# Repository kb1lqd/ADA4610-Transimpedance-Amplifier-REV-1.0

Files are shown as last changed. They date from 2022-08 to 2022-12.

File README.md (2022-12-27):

Notes

# 2022-08-23

* Soldered the board together
* It works! But I did find some minor errors.
* The voltage output varies as expected with light over a wide range

## Errors
* D1 footprint pin 1 assingment is backwards, this resulted in the diode being backwards
* The resulting current from the device is quite large resulting in the second amplifier stage being saturate in a lit room, I removed R7 to create a voltage follower and this alleviate the issues for now
* Placing the output on a scope it's clear there is a HF oscillation at 2.24mHz
** NOTE that the oscillation appears to be only on the 2nd stage output and not the first stage. Note that the second stage is now a voltage follower

# 2022-08-24

* Placed a 33pF capacitor across R8 and this stopped the oscillation
* I repopulated R7 with a 1K resistor
* There is some very very high frequency noise but pretty negligable it seems
* It works! I can definetley see an IRDA remote control signal at ~37KHz carrier
* It seems like if I want to use this in a bright room I'm going to have to turn the gains down
** Which is better - the TIA or the second stage?

# 2022-10-03

I've built up a bit of infrastructure around this TIA:
* Headphone amplifier to output the audio frequencies directly into headphones
* Listened to external light sources with a len assembly 3 miles away
* Built a simple audio light transmitter

I've noticed a faire bit of noise in the circuit. Hooking a scope up to the TP output I see a fairly complex oscillation between 30KHz and 97KHz. There is a different noise on the TIA output directly much smaller prior to the line driver amplifier.

**Noise on the TIA PCB 50 Ohm Output***

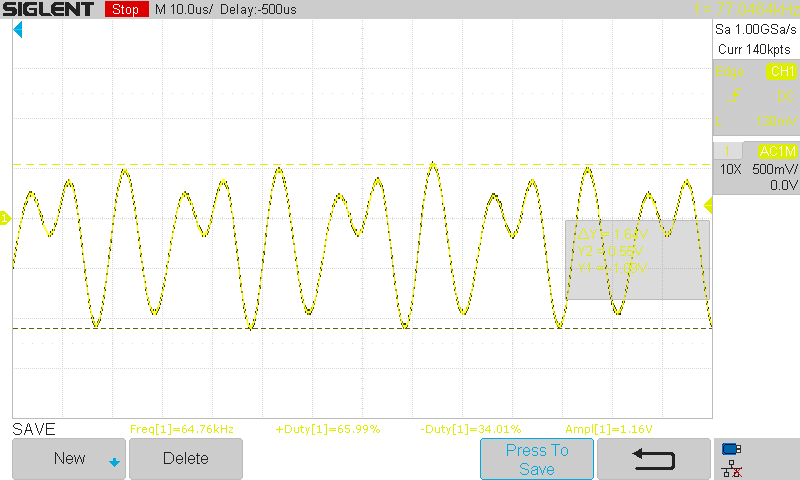
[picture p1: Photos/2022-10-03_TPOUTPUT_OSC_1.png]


**Noise on the TIA Output directly**

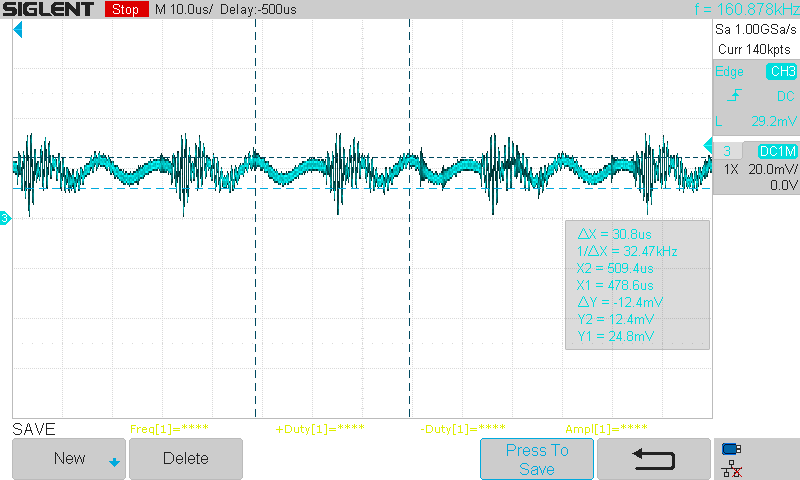
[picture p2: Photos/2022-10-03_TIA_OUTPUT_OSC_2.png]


I can see and hear the 120 Hz hum from my indoor (dim) lights that this noise is on top of.

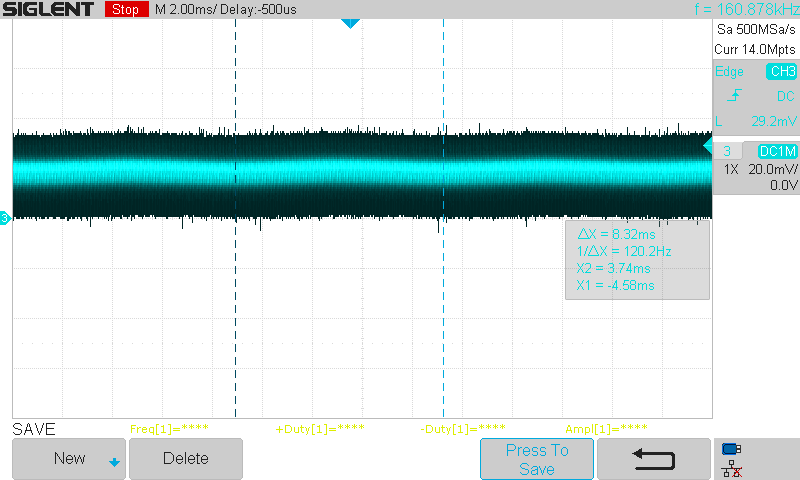
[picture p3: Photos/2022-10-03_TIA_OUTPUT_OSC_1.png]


# 2022-10-04

* I put the recommended bulk capacitors on the PYBE20-Q24-D5-T - No significant change but leaving them There
* I think it may have knocked a bit of the switching noise off
  * I defintely see a 32KHz DC/DC switching noise but it's near my scopes limit
  * It is seen on the preamp section op-amp bulk capacitors and in the TIA signal itself - It may be ground noise coming through the GND clip...?
  * Placing bulk capacitance on the preamp - no effect
* I added a 15pF capacitor to C2 to help bypass any HF signals past the 0 ohm or stabalize the POS input when in a higher impedance configuration
* I changed the Cf on the TIA (C4) from 3.3pF to 33pF for improved stability - No significant change - The nosie see is the same and defintely switching noise (likley on GND)
* I iterated a Cf across R8 and found that a 1nF completely kills the oscillation see - Tried ~200pF with good results but sign reduced from ~300mV to 60mV peak to peak.

I'm getting subjectively reduced noise!

I can clearly head music and tones from an online frequency generator through the transmitter (Although I don't think it's fully modulating the LED)

I listened to a few signals:

**iPhone FaceID Pulses**

The pulses are very clear (DC Coupled scope after the DC blocking capacitor) with a rise time of 92us (~3KHz)

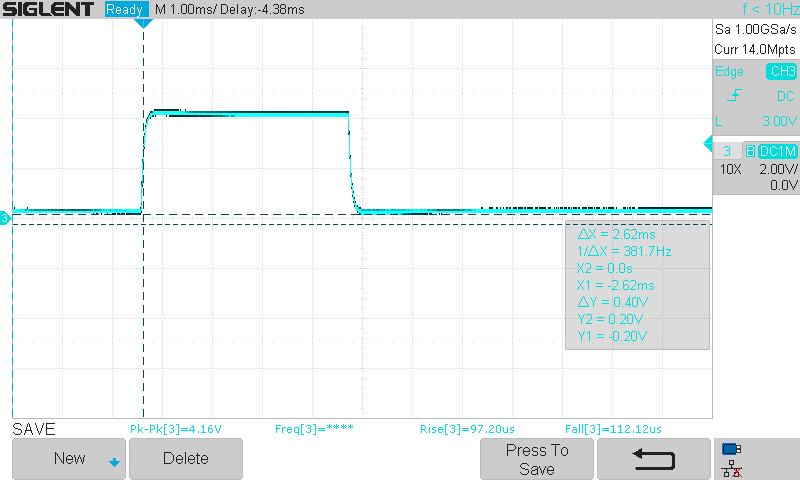
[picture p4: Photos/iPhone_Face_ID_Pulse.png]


**Optical Mouse LED/LASER**

This was much quicker of a signal and measured around 3.6us which is approximately (0.35/Tr) 100KHz bandwidth. I don't know what this signal looks linear.

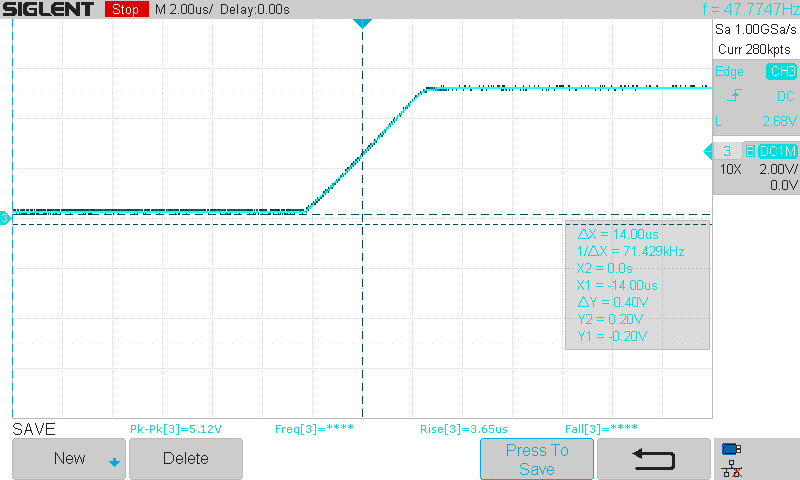
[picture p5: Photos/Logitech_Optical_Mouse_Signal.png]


# 2022-12-26

* I soldered a new TIA PCB together (Ver1.1) with just U1 TIA. I found that the TIA was stable at RF=10K and CF=6.6pF with the diode in photovoltaic mode (grounded) and the TIA V+ referenced to GND. This configuration did require U1 to operate with a split rail.
* I was wrong in the prior testing and it seemed that the U2 second stage was LPF'ing the 37KHz IRDA signals. I was clearly able to see the IRDA waveforms (still looked RC charged/discharged but that might have been the IR remote itself - More investigation needed.

# To-Do
* [DONE] Track down oscillation
* [DONE] Detect light pulses in the scope and observe the results
* Detemirne rough frequency response - even if simulated with updated values (37KHz carrier pulses looked pretty rounded) - This may inform a reduction in capacitances or resistances)

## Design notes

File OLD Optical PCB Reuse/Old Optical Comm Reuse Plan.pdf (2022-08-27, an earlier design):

# Old Optical Comm Reuse Plan

## Headphone Audio - Aug 2022

## TPA6111A2D Headphone Amp

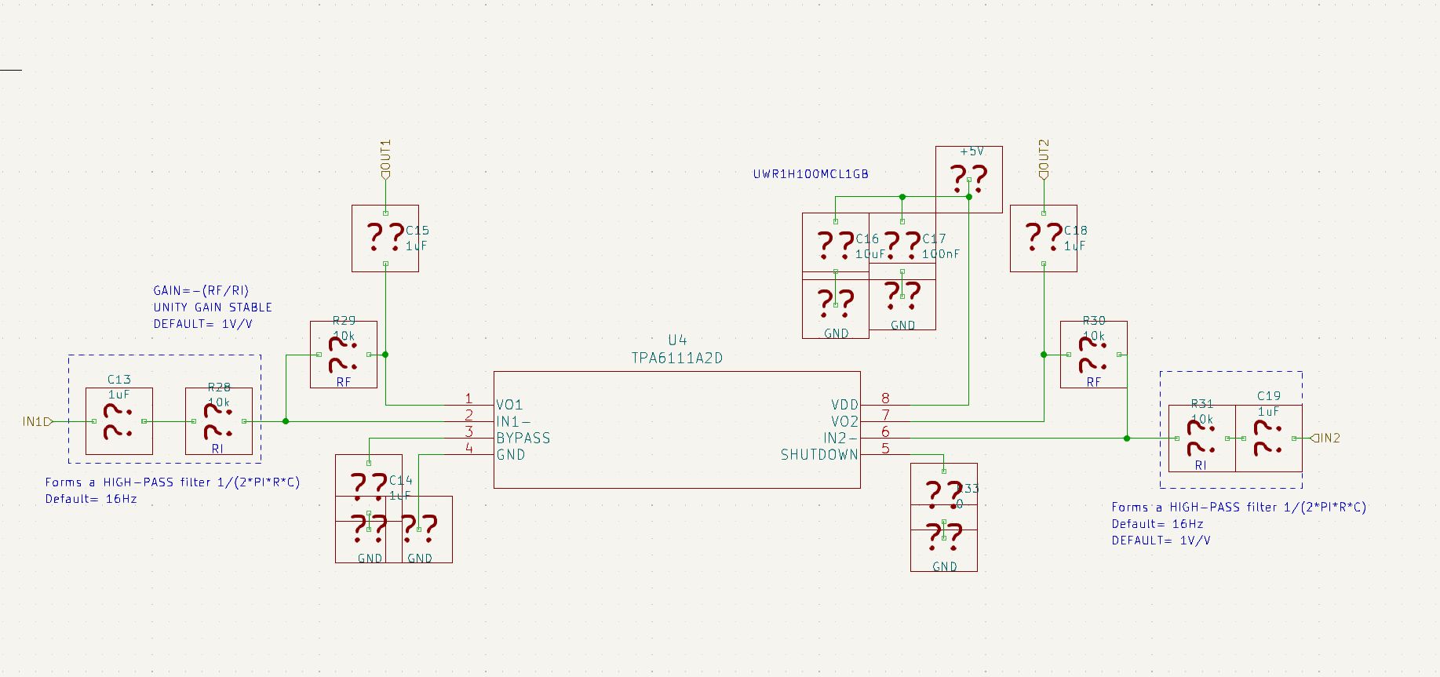
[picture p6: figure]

## Where to tap in

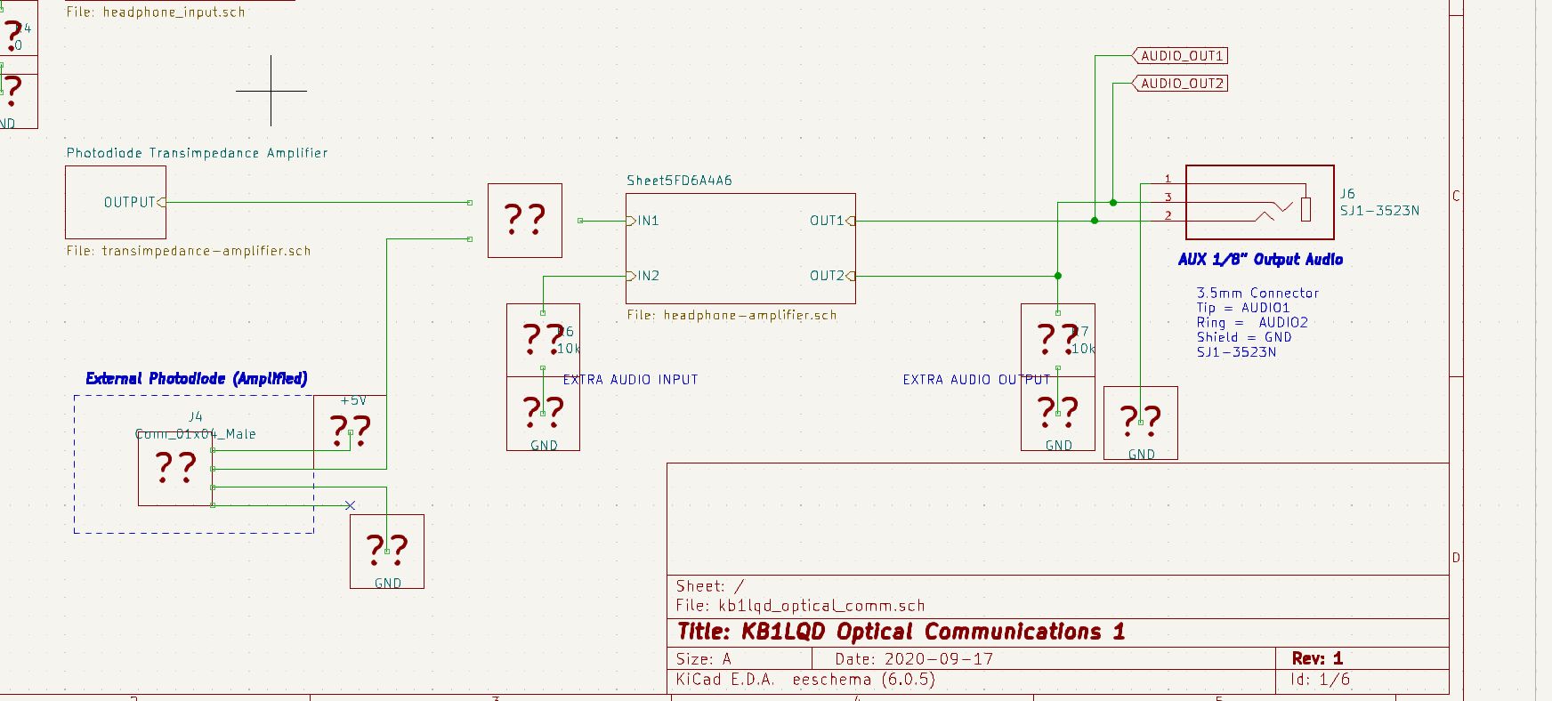
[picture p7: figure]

- Use connector J4 to get TIA signal in
- Jump the SW prior to IN1
- Short IN1 to IN2 for dual headphone?
- Use J6

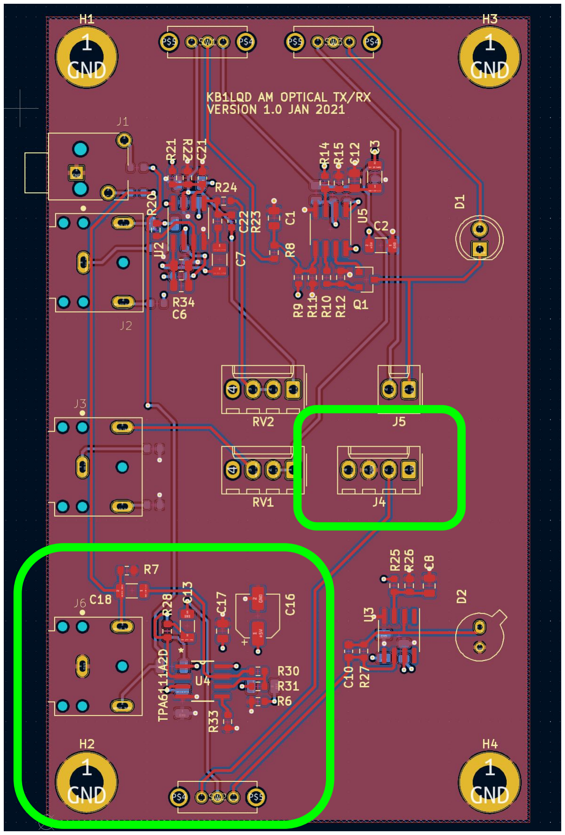
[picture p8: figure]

- J4 can input
- Signal
- +5V
- GND
●

## LED Driver?

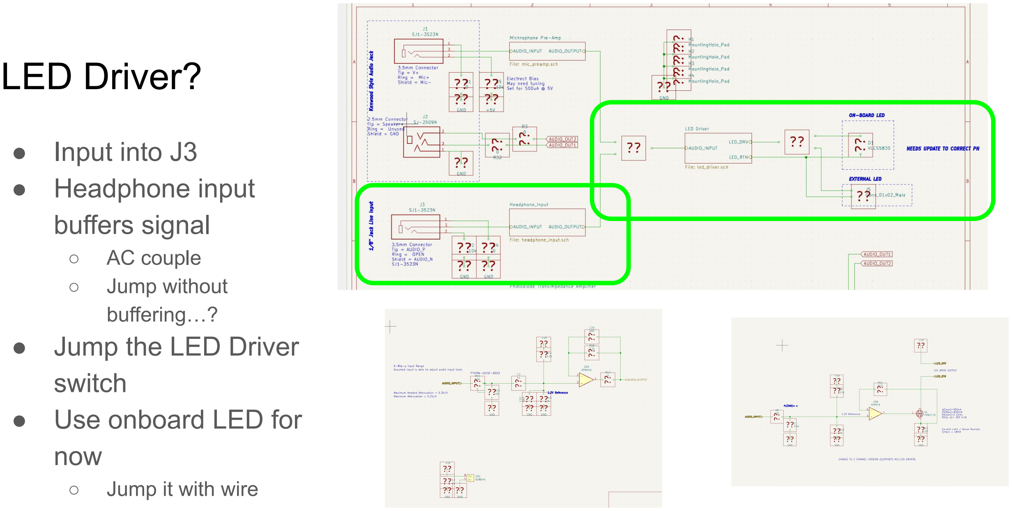
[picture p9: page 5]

- Input into J3
- Headphone input
buffers signal
- AC couple
- Jump without
buffering…?
- Jump the LED Driver
switch
- Use onboard LED for
now
- Jump it with wire

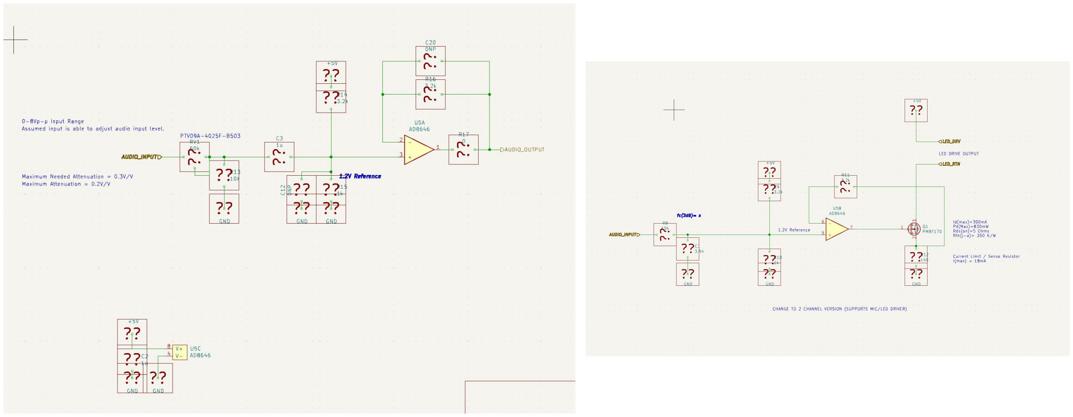
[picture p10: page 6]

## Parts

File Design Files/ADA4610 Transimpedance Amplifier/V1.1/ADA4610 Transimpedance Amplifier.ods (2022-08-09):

Item | Qty | Reference(s) | Value | PN Assigned | From Where? | Package | Footprint Done? | Ordered?
1 | 2 | C1, C3 | 1u | C1206X105M1RAC7800 | Brent’s Inventory | 1206 | Yes | N/A
2 | 1 | C2 | 100n | C0805C104Z4VAC7800 | Digikey | 805 | Yes | In List
3 | 1 | C4 | 3.3p | 06035A3R3KAT2A | Digikey | 603 | Yes | In List
4 | 1 | C5 | 10u | CL32A106KBJNNNE | Digikey | 1210 | Yes | In List
5 | 2 | C6, C7 | 1u | C1206X105M1RAC7800 | Brent’s Inventory | 1206 | Yes | N/A
6 | 1 | D1 | ODD-1W | ODD-1W | Brent’s Inventory | ODD-1W |  | N/A
7 | 4 | H1, H2, H3, H4 | MountingHole |  | Brent’s Inventory | N/A | Yes | N/A
8 | 1 | J1 | Conn_01x03_Male | KK | Brent’s Inventory | KK | Yes | N/A
9 | 1 | J2 | Conn_Coaxial | CON-EDGE-SMA-5 | Brent’s Inventory | CON-EDGE-SMA-5 |  | N/A
10 | 3 | R1, R2, R5 | 0 | RC0603FR-130RL | Brent’s Inventory | 603 | Yes | N/A
11 | 2 | R3, R4 | 10k | RC0603FR-1010KL | Brent’s Inventory | 603 | Yes | N/A
12 | 1 | R6 | 100k | RC0805JR-07100KL | Brent’s Inventory | 805 | Yes | N/A
13 | 1 | R7 | 1k | RC0603FR-131KL | Brent’s Inventory | 603 | Yes | N/A
14 | 1 | R8 | 49.9k | ERJ-PB6D4992V | Digikey | 805 | Yes | In List
15 | 2 | R9, R10 | 49.9 | ERJ-6ENF49R9V | Digikey | 805 | Yes | In List
16 | 7 | TP1, TP2, TP3, TP4, TP5, TP6, TP7 | TestPoint | 36-5010-ND | Digikey | 36-5010-ND | Yes | In List
17 | 2 | U1, U2 | ADA4610-1xR |  | Brent’s Inventory | SOT-23-5 | Yes | N/A

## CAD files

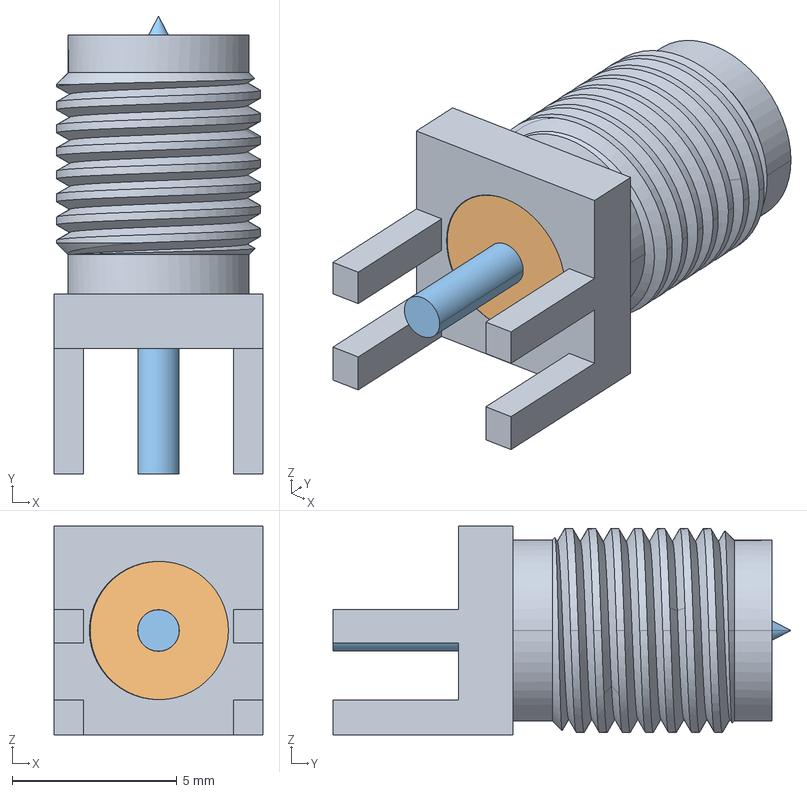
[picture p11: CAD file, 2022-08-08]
Components/CON-EDGE-SMARP-3D file - Copy.stp
6.35 x 13.9 x 6.35 mm
SMA-K-KE
JIAOLI
RP-ZHEN

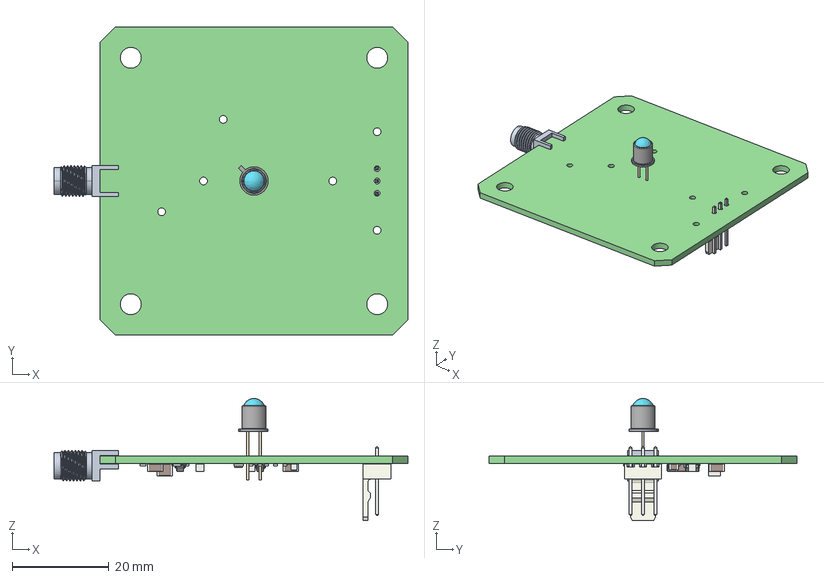
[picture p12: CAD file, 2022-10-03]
Design Files/ADA4610 Transimpedance Amplifier/V1.1/ADA4610 Transimpedance Amplifier.step
73.0 x 63.5 x 25.2 mm
ADA4610 Transimpedance Amplifier PCB

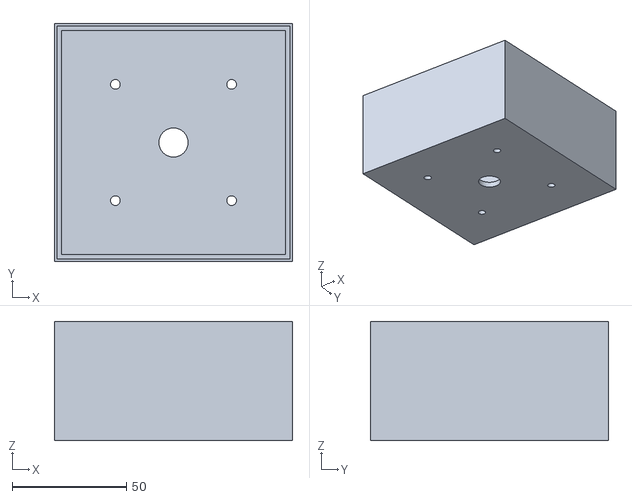
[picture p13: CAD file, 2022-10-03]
Design Files/ADA4610 Transimpedance Amplifier/V1.1/Lens Mount/Lensmount-ModelPCB Mount001.stl
104.0 x 104.0 x 52.0

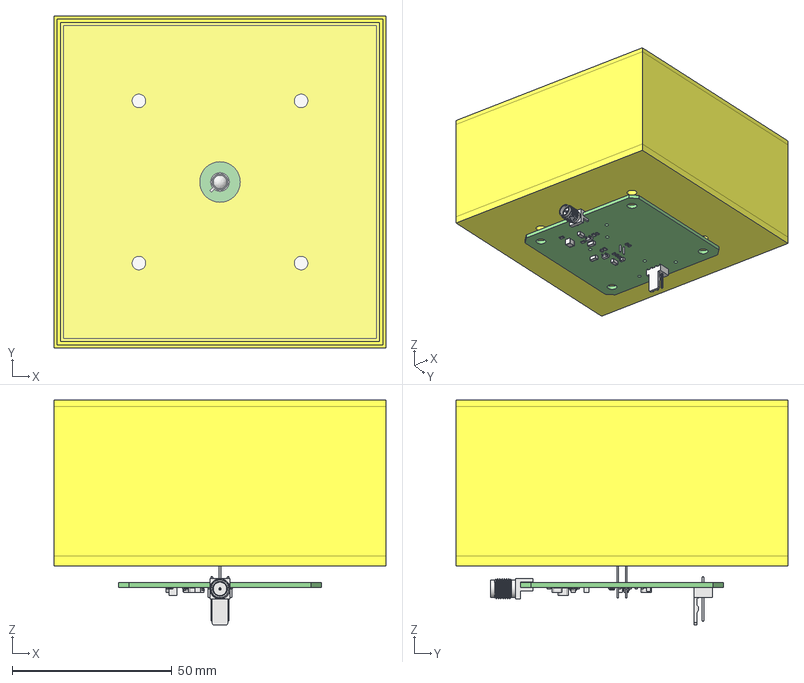
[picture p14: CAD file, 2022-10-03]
Design Files/ADA4610 Transimpedance Amplifier/V1.1/Lens Mount/Lensmount.FCStd
104.0 x 104.0 x 70.5 mm
PCB Mount
Lens
ADA4610 Transimpedance Amplifier PCB

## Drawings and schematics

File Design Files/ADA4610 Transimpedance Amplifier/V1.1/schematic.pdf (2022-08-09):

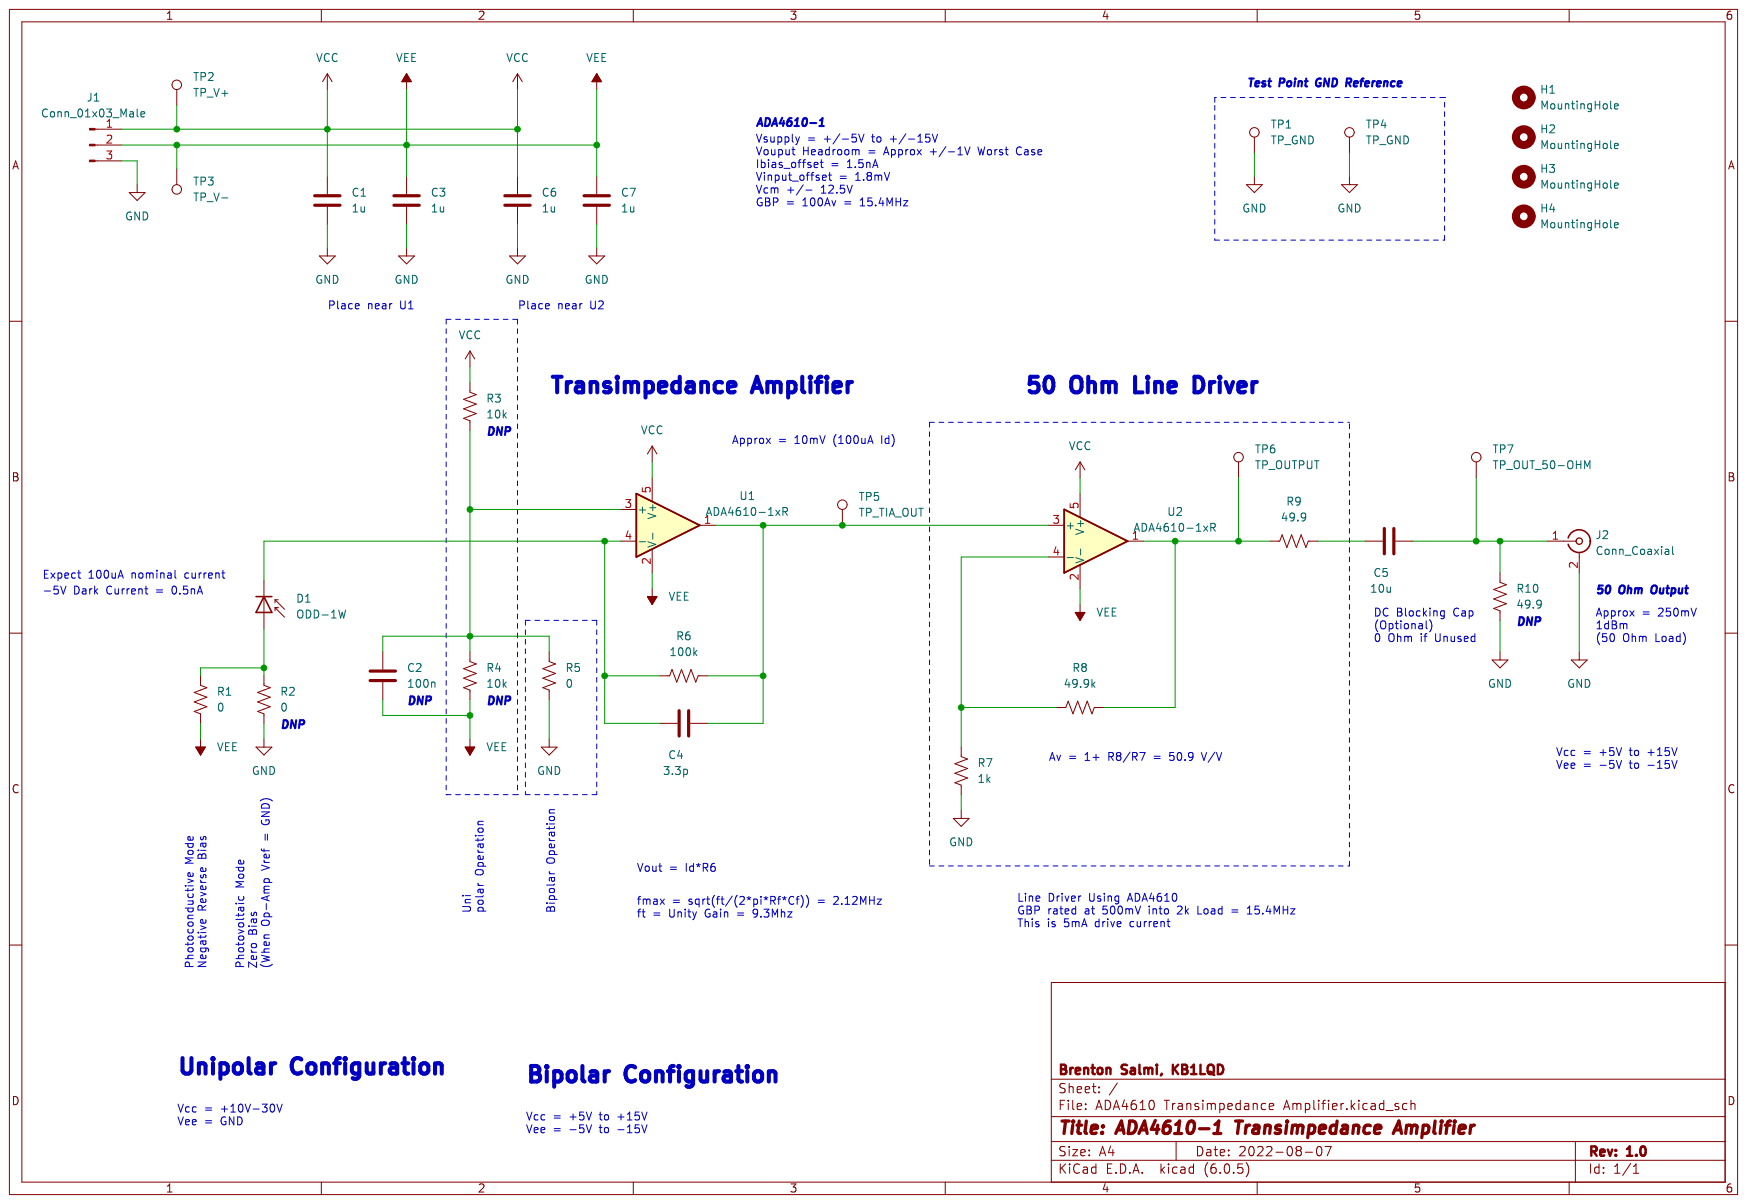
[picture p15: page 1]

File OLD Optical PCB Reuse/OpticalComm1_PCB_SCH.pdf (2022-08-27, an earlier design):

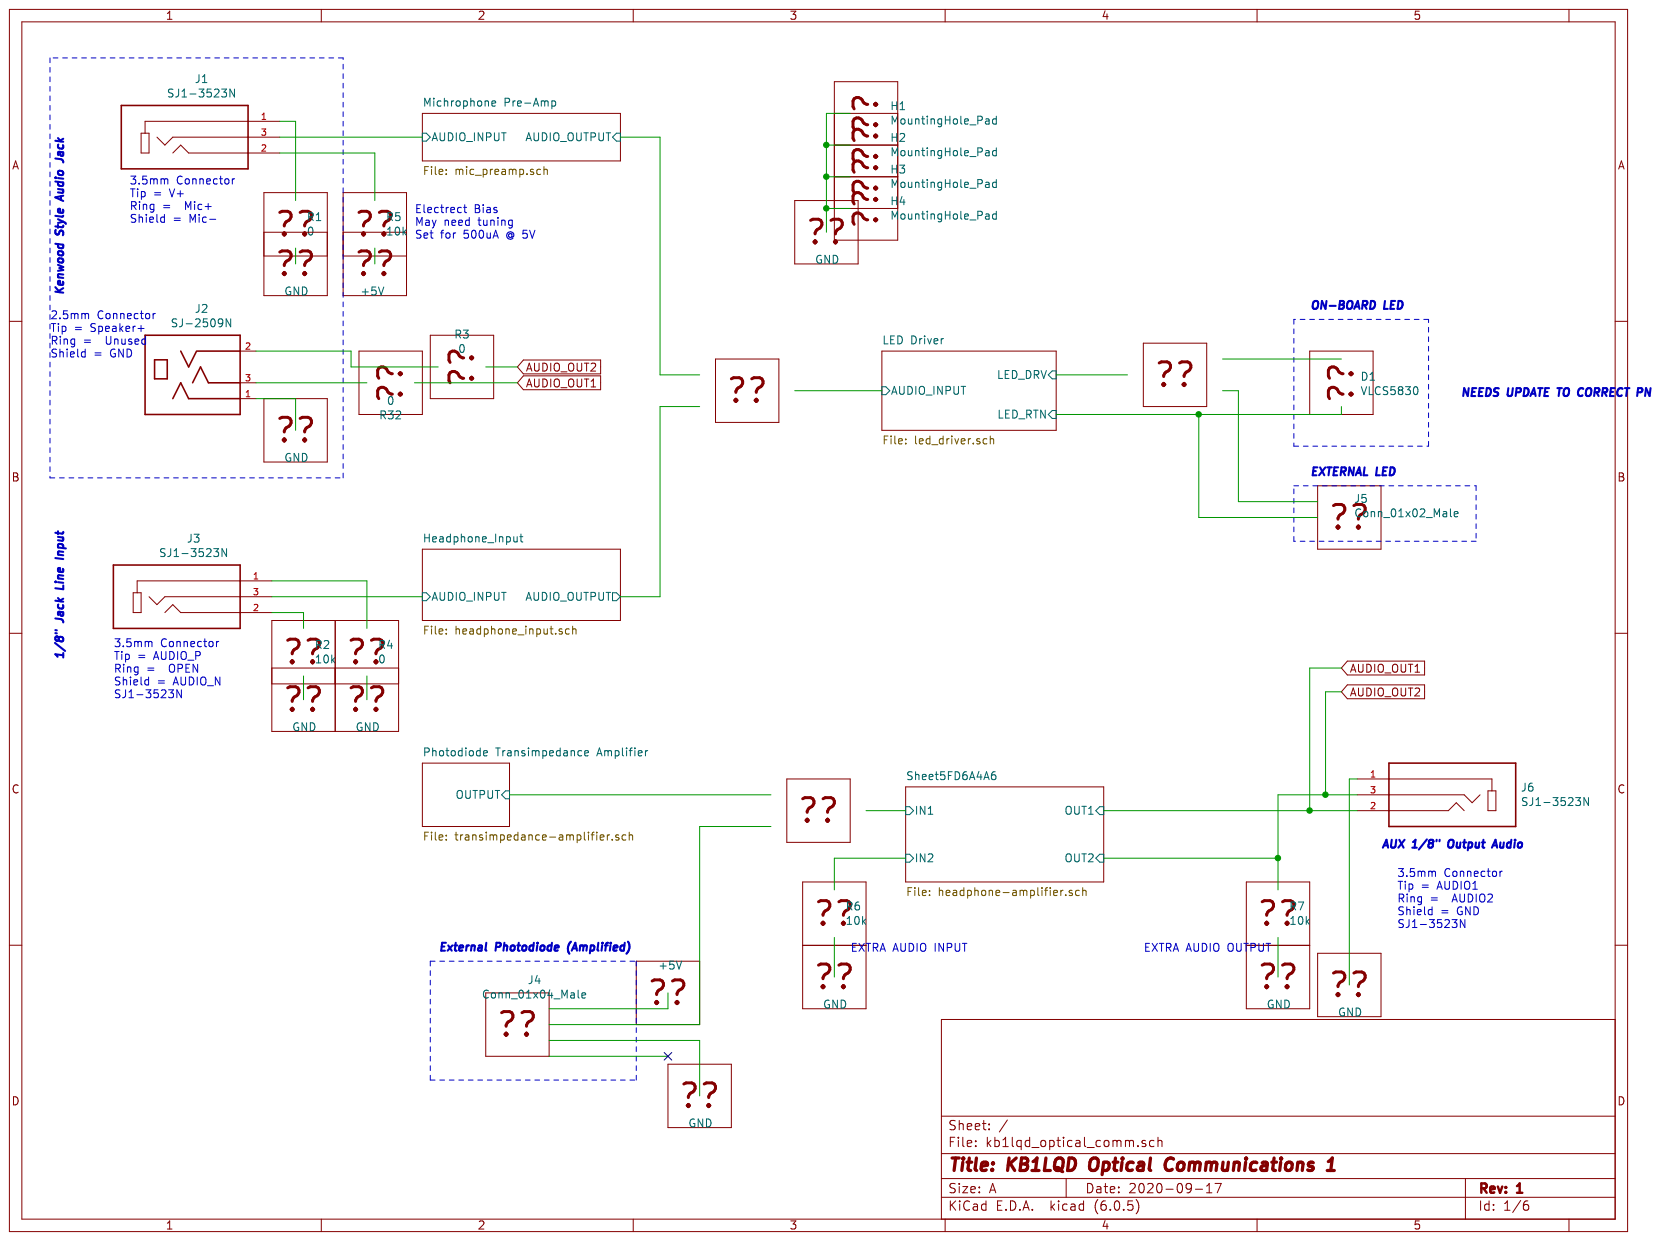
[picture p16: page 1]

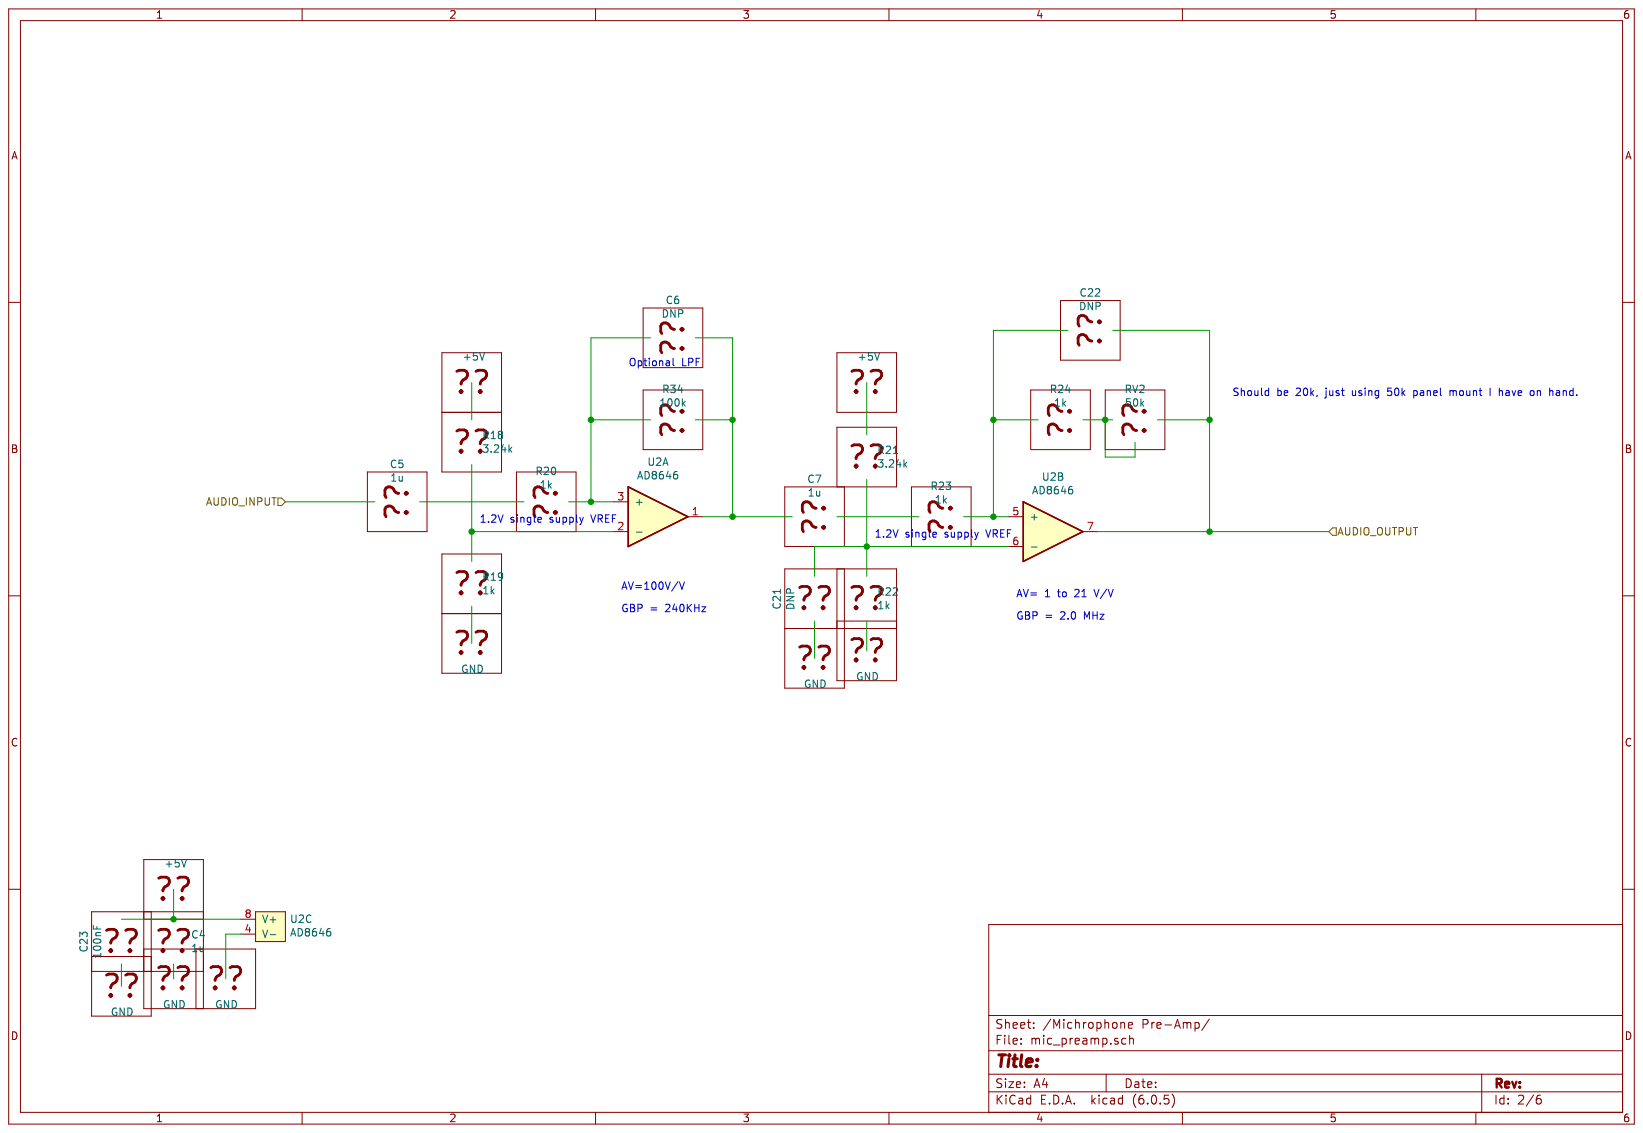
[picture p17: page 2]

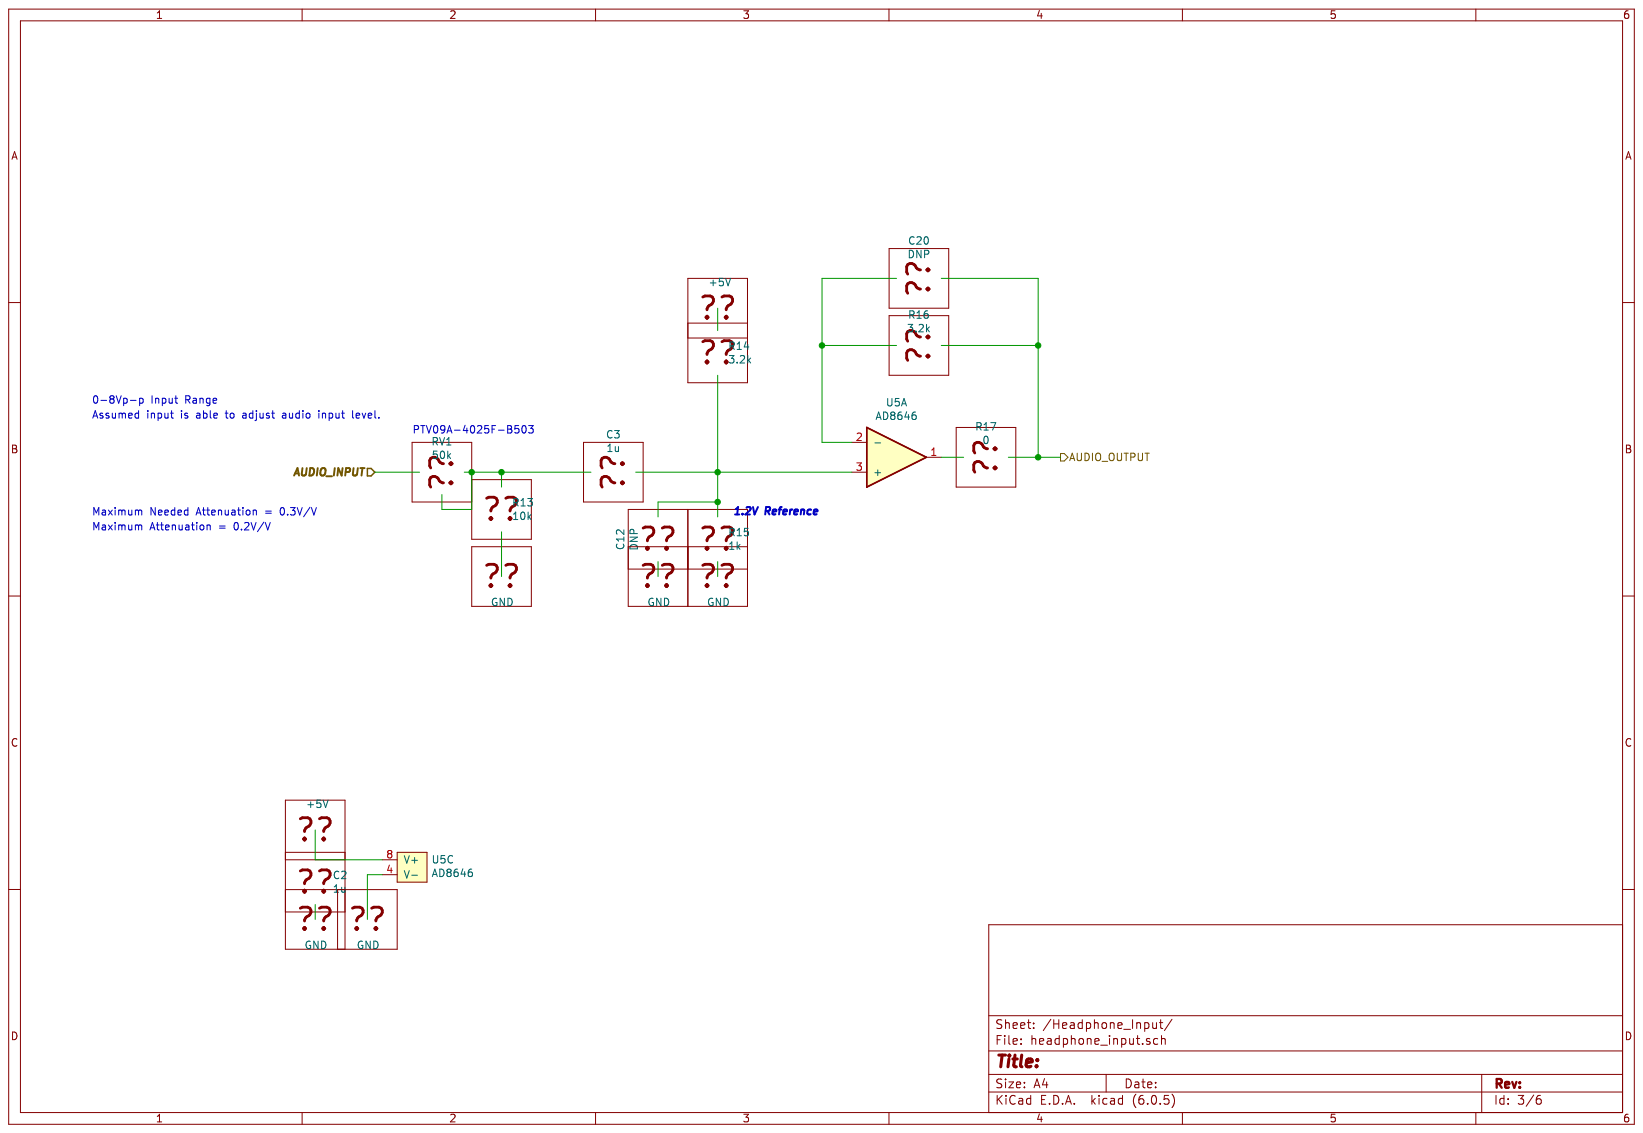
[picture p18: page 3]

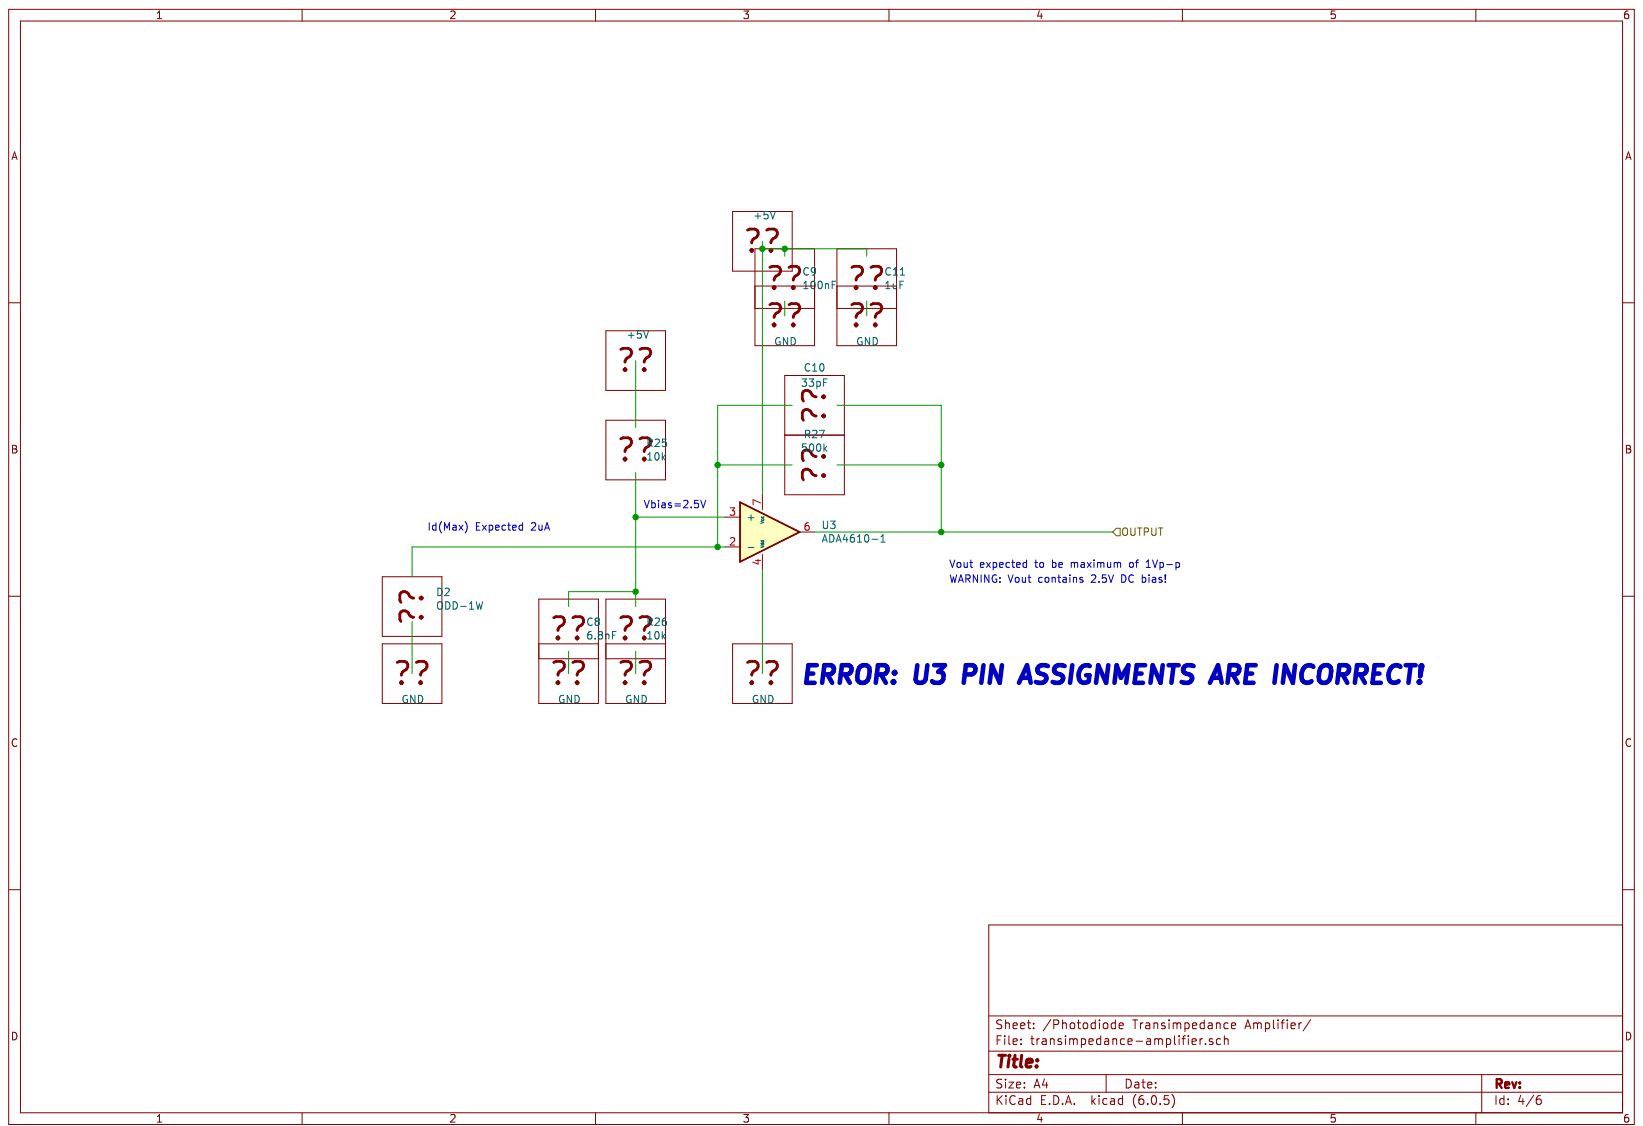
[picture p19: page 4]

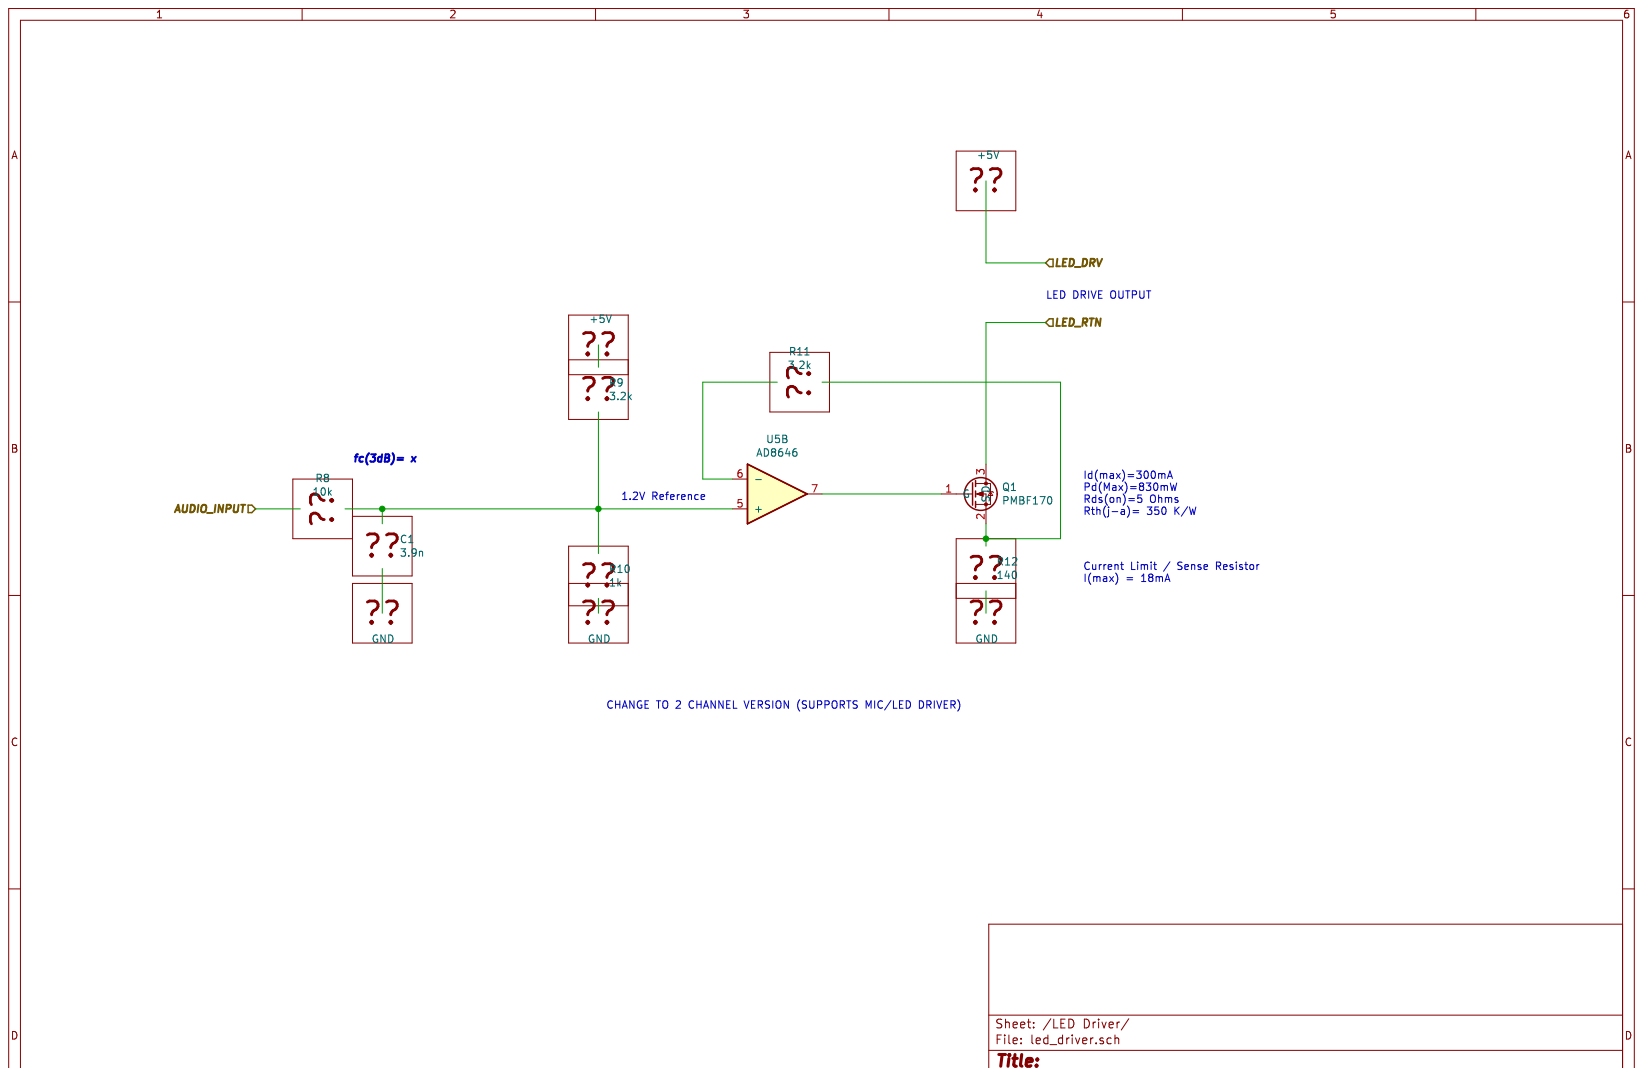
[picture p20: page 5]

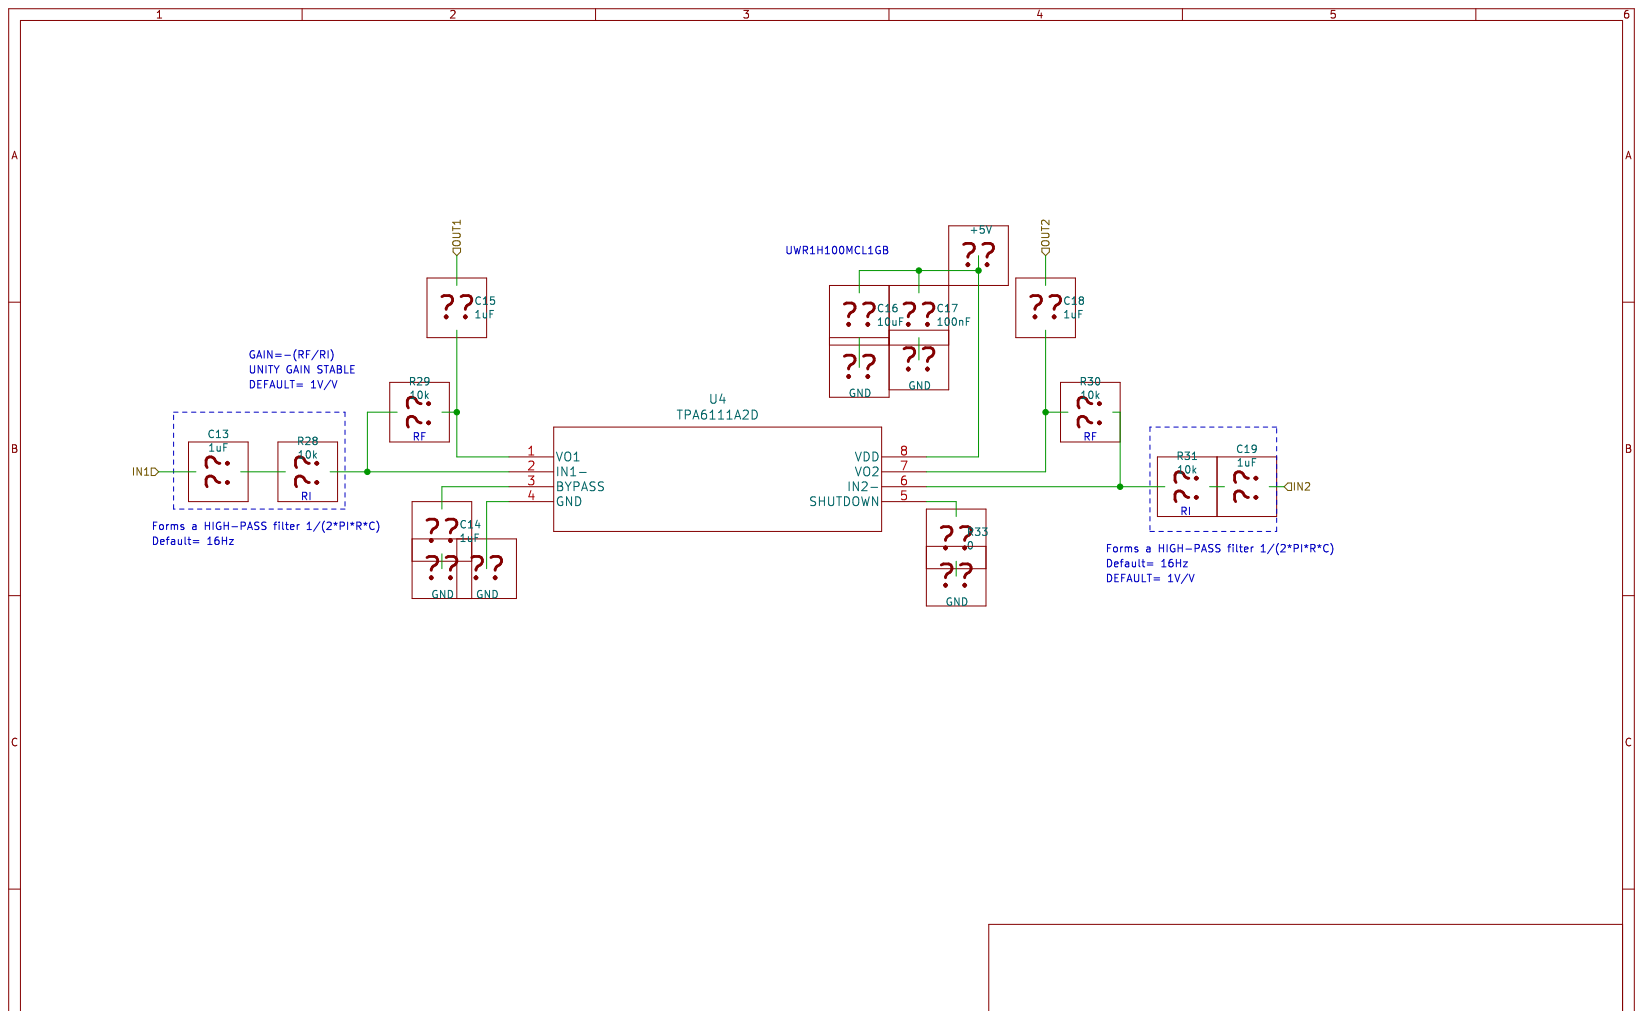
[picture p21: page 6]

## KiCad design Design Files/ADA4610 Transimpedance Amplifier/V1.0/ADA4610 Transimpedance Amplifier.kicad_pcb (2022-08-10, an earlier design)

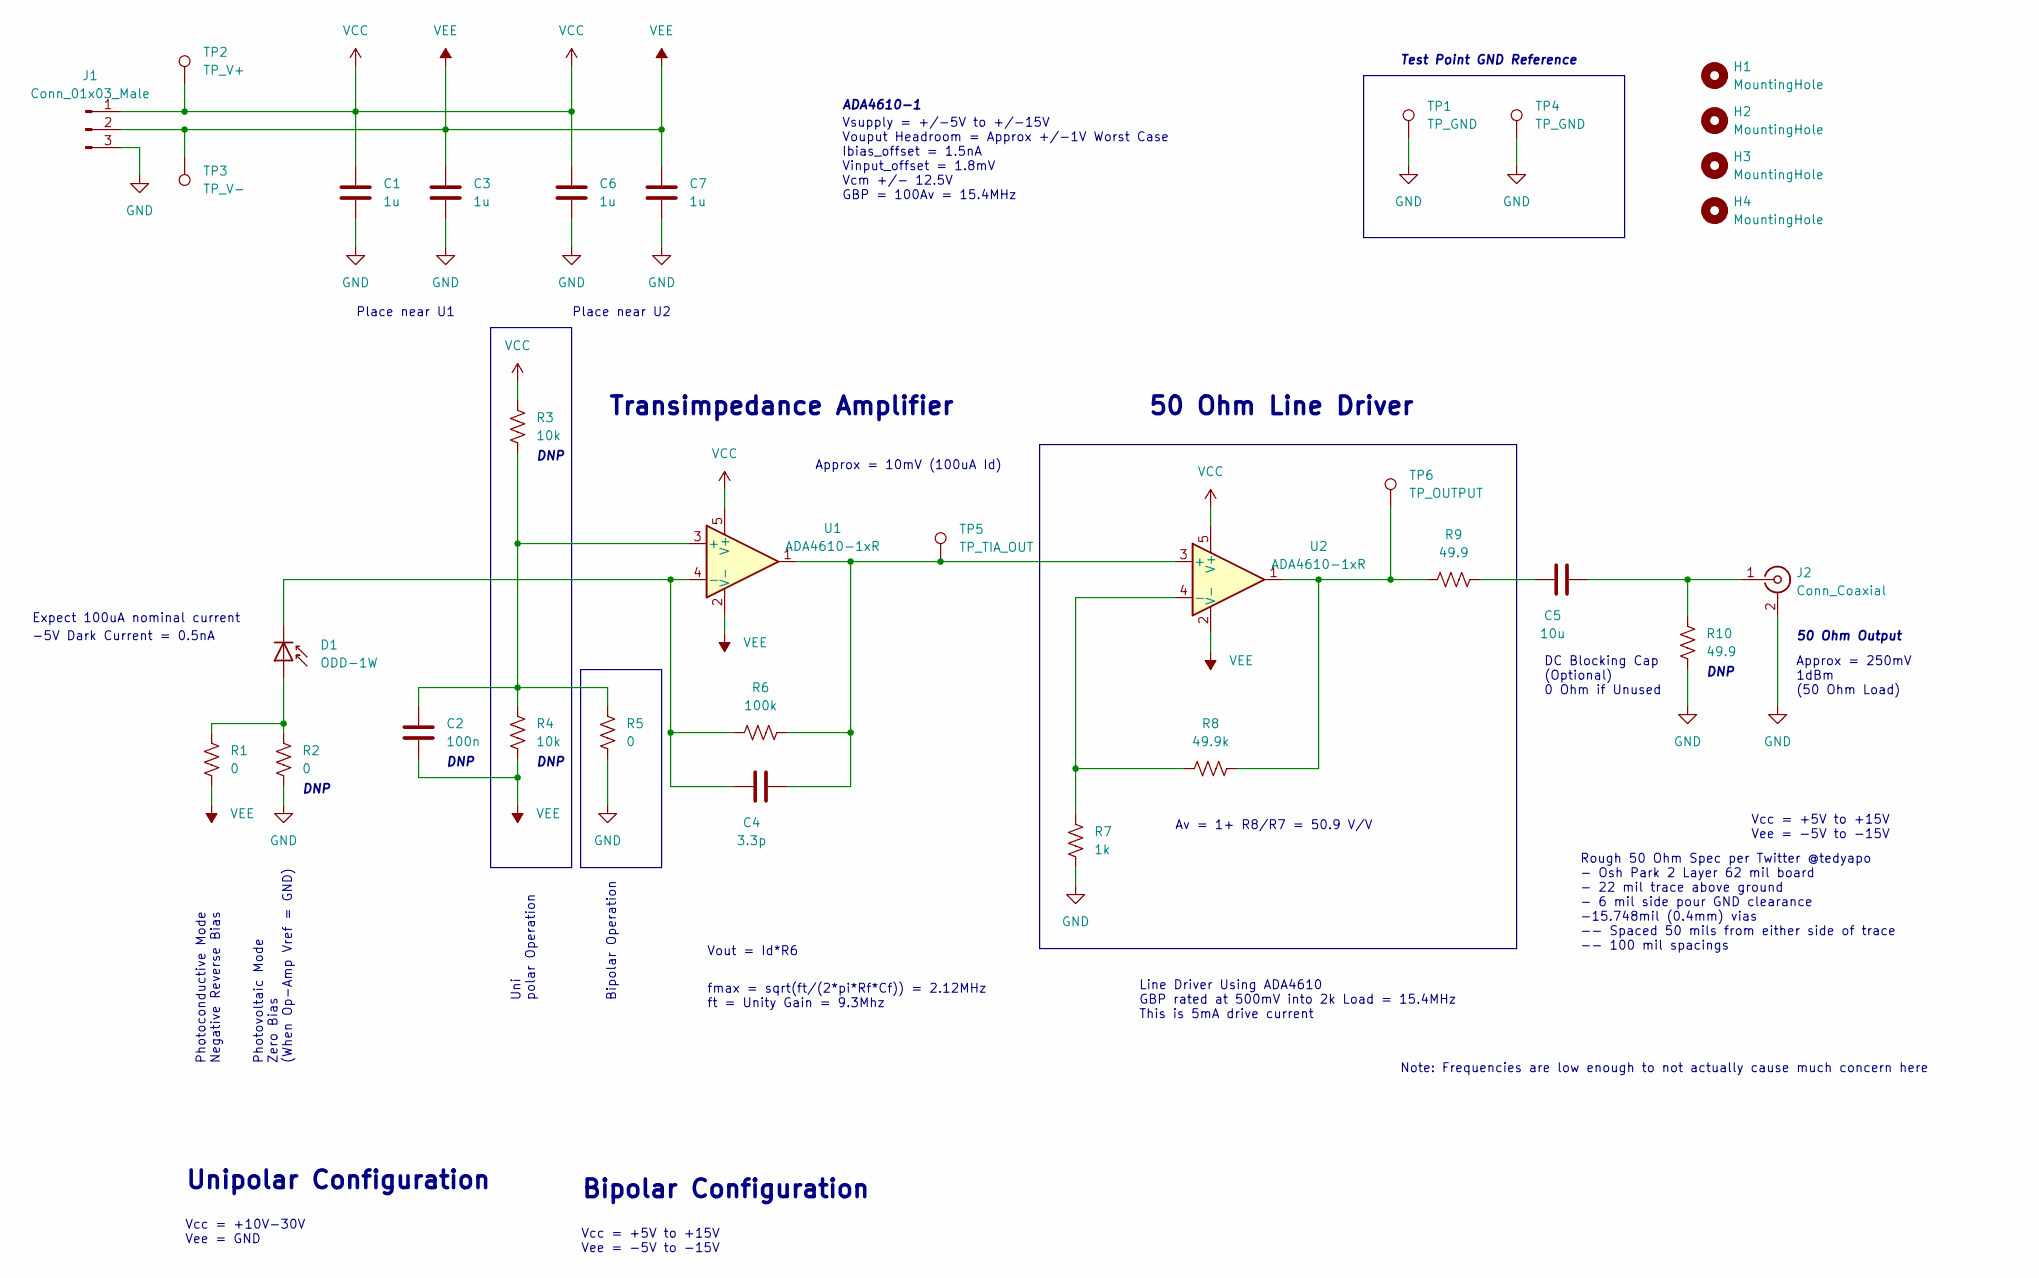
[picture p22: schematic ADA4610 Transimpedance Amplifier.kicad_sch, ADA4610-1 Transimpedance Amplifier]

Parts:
C1, C3, C6, C7: 1u; C_1206_3216Metric_Pad1.33x1.80mm_HandSolder
C2: 100n; C_0805_2012Metric_Pad1.18x1.45mm_HandSolder
C4: 3.3p; C_0603_1608Metric_Pad1.08x0.95mm_HandSolder
C5: 10u; C_1210_3225Metric_Pad1.33x2.70mm_HandSolder
D1: ODD-1W; TO-18-2_Lens_Centered
H1, H2, H3, H4: MountingHole; MountingHole_4.3mm_M4
J1: Conn_01x03_Male; Molex_KK-254_AE-6410-03A_1x03_P2.54mm_Vertical
J2: Conn_Coaxial; RFSOLUTIONS_CON-SMA-EDGE-S
R1, R2, R5: 0; R_0603_1608Metric_Pad0.98x0.95mm_HandSolder
R3, R4: 10k; R_0603_1608Metric_Pad0.98x0.95mm_HandSolder
R6: 100k; R_0805_2012Metric_Pad1.20x1.40mm_HandSolder
R7: 1k; R_0603_1608Metric_Pad0.98x0.95mm_HandSolder
R8: 49.9k; R_0805_2012Metric_Pad1.20x1.40mm_HandSolder
R9, R10: 49.9; R_0805_2012Metric_Pad1.20x1.40mm_HandSolder
TP1, TP4: TP_GND; TestPoint_Keystone_5010-5014_Multipurpose
TP2: TP_V+; TestPoint_Keystone_5010-5014_Multipurpose
TP3: TP_V-; TestPoint_Keystone_5010-5014_Multipurpose
TP5: TP_TIA_OUT; TestPoint_Keystone_5010-5014_Multipurpose
TP6: TP_OUTPUT; TestPoint_Keystone_5010-5014_Multipurpose
U1, U2: ADA4610-1xR; SOT-23-5

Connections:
GND: C1.1, C3.1, C6.1, C7.1, J1.3, J2.2 (Ext), R2.2, R5.2, R7.1, R10.2, TP1.1, TP4.1
unnamed: C2.2, R3.2, R4.1, R5.1, U1.3 (+)
unnamed: C4.1, D1.1 (K), R6.1, U1.4 (-)
unnamed: C4.2, R6.2, TP5.1, U1.1, U2.3 (+)
unnamed: C5.1, R9.1
unnamed: C5.2, J2.1 (In), R10.1
unnamed: D1.2 (A), R1.1, R2.1
unnamed: R7.2, R8.2, U2.4 (-)
unnamed: R8.1, R9.2, TP6.1, U2.1
VCC: C1.2, C6.2, J1.1, R3.1, TP2.1, U1.5 (V+), U2.5 (V+)
VEE: C2.1, C3.2, C7.2, J1.2, R1.2, R4.2, TP3.1, U1.2 (V-), U2.2 (V-)

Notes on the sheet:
50 Ohm Output
Uni polar Operation
50 Ohm Line Driver
DNP
DC Blocking Cap (Optional) 0 Ohm if Unused
Approx = 10mV (100uA Id)
Note: Frequencies are low enough to not actually cause much concern here
Vcc = +5V to +15V Vee = -5V to -15V
Line Driver Using ADA4610 GBP rated at 500mV into 2k Load = 15.4MHz This is 5mA drive current
Unipolar Configuration
Rough 50 Ohm Spec per Twitter @tedyapo - Osh Park 2 Layer 62 mil board - 22 mil trace above ground - 6 mil side pour GND clearance -15.748mil (0.4mm) vias -- Spaced 50 mils from either side of trace -- 100 mil spacings
Bipolar Operation
fmax = sqrt(ft/(2*pi*Rf*Cf)) = 2.12MHz ft = Unity Gain = 9.3Mhz
Vsupply = +/-5V to +/-15V Vouput Headroom = Approx +/-1V Worst Case Ibias_offset = 1.5nA Vinput_offset = 1.8mV Vcm +/- 12.5V GBP = 100Av = 15.4MHz
ADA4610-1
Test Point GND Reference
Place near U2
Vout = Id*R6
Photovoltaic Mode Zero Bias (When Op-Amp Vref = GND)
Photoconductive Mode Negative Reverse Bias
Expect 100uA nominal current
Transimpedance Amplifier
Av = 1+ R8/R7 = 50.9 V/V
Bipolar Configuration
-5V Dark Current = 0.5nA
Approx = 250mV 1dBm (50 Ohm Load)
Vcc = +10V-30V Vee = GND
Place near U1

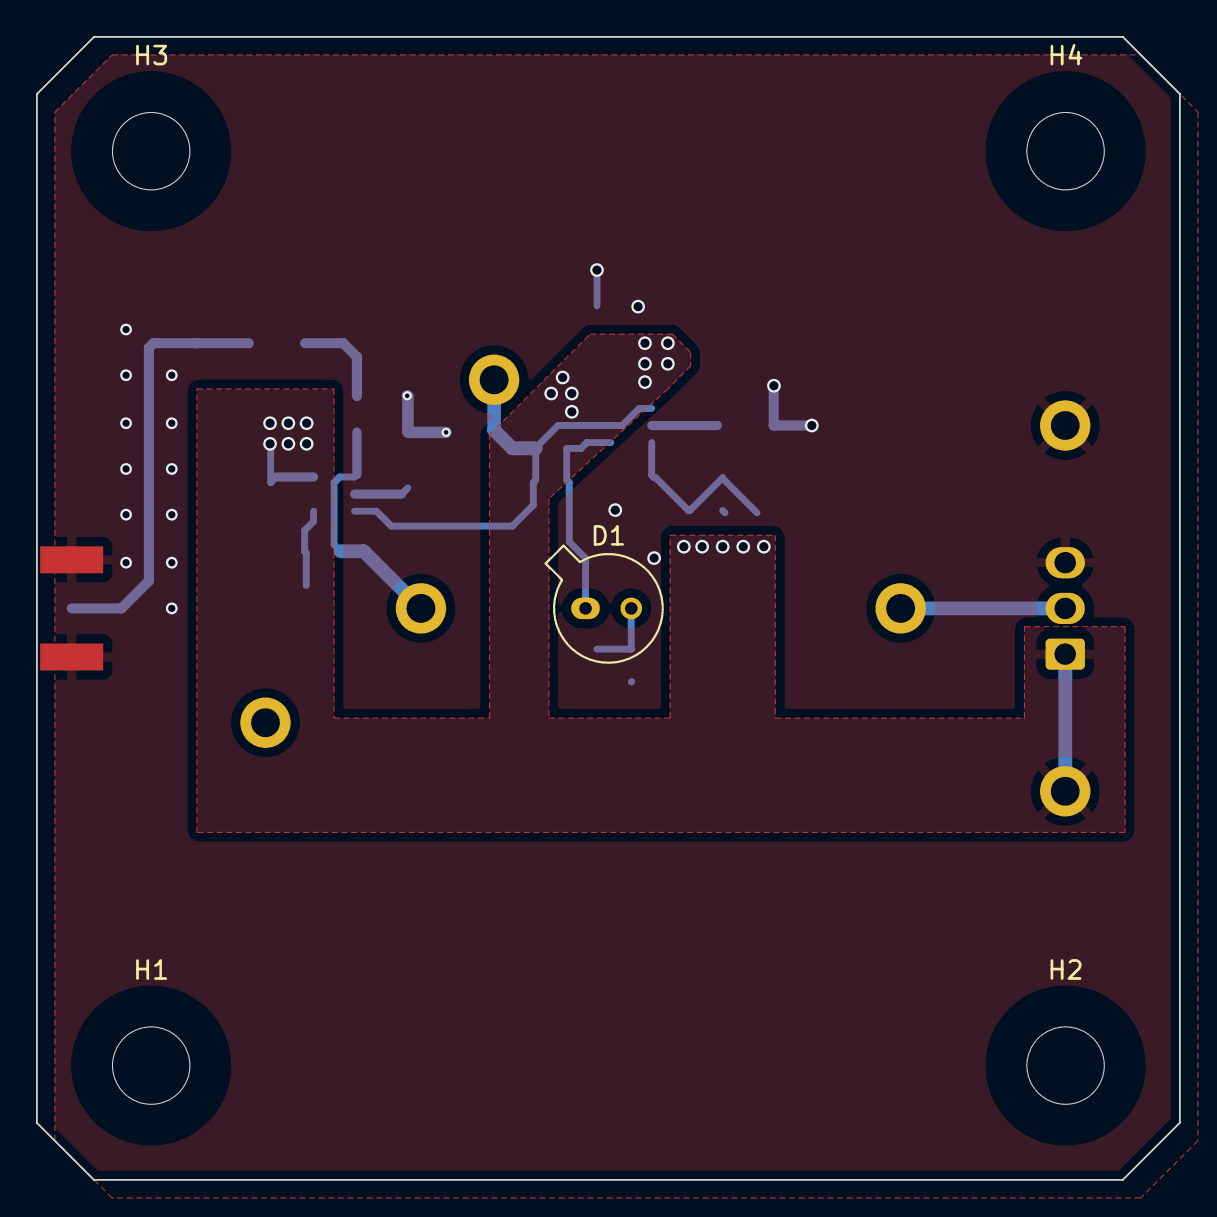
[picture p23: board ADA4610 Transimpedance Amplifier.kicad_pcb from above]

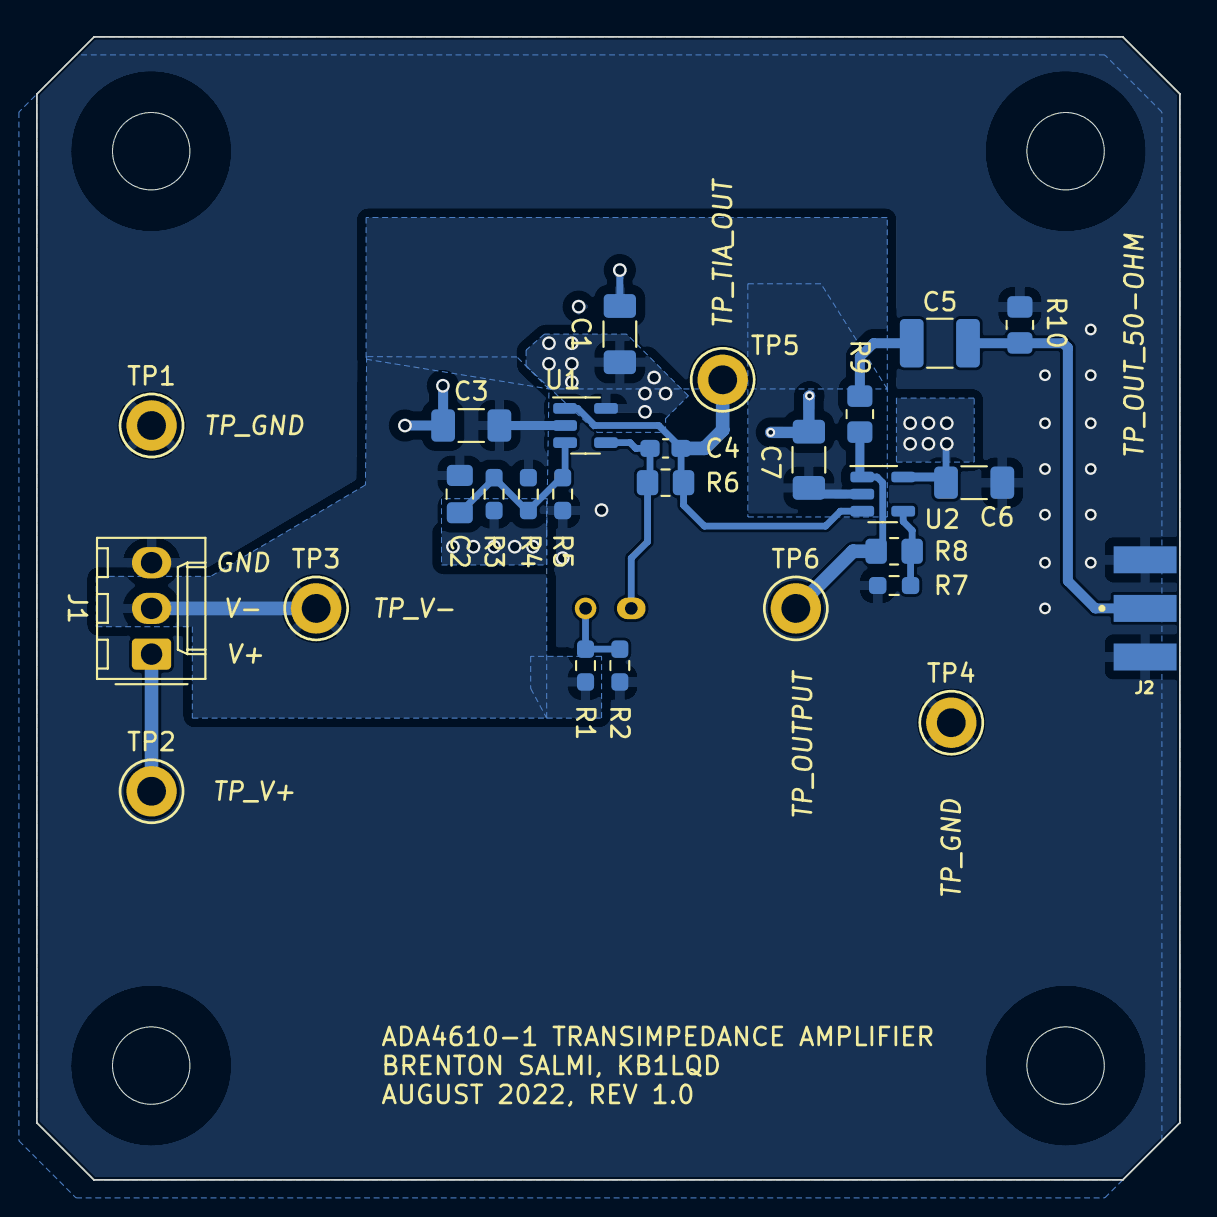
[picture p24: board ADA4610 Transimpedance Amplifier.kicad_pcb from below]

Board: 2 copper layers, 63.5 x 63.5 mm, 32 parts (27 on the bottom side), 11 nets.

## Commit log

2022-08-07 Initial commit.
    Basic transimpedance amplifier and line driver.
    [ADA4610 Transimpedance Amplifier.kicad_pcb, ADA4610 Transimpedance Amplifier.kicad_sch]
2022-08-07 Initial pass finished.
    Finished the initial schematic and scope. Also did some simulations. Google drive has the dBm output calculations.
    [ADA4610 Transimpedance Amplifier.kicad_sch]
2022-08-08 Assigned most footprints - picked parts.
    [ADA4610 Transimpedance Amplifier.kicad_sch, ADA4610 Transimpedance Amplifier.ods]
2022-08-08 All components and footprints assigned and created. Layout imported parts.
    [ADA4610 Transimpedance Amplifier.kicad_pcb, ADA4610 Transimpedance Amplifier.kicad_sch, CON-EDGE-SMARP-3D file - Copy.stp]
2022-08-09 Imported Mcmaster carr shelving brackets for an initial fit.
    [ADA4610 Transimpedance Amplifier.ods]
2022-08-09 Gave a quick schematic review
    [ADA4610 Transimpedance Amplifier.kicad_sch]
2022-08-09 Initial Placement Done.
    [ADA4610 Transimpedance Amplifier.kicad_pcb, ADA4610 Transimpedance Amplifier.kicad_sch]
2022-08-09 Placement and text completed.
    Ready for traces.
    [ADA4610 Transimpedance Amplifier.kicad_pcb, ADA4610 Transimpedance Amplifier.kicad_sch]
2022-08-10 Updated PCB to osh park 2 layer rules.
    [ADA4610 Transimpedance Amplifier.kicad_pcb]
2022-08-10 Board completed and no errors.
    [ADA4610 Transimpedance Amplifier.kicad_pcb, ADA4610 Transimpedance Amplifier.kicad_sch]
2022-08-25 Update README.md
    Working PCBA updates.
2022-08-27 Adding old pcb optical comm reuse plan.
2022-08-27 Adding as built TPA611A2 audio amp.
    [TPA6111A2D_Protoboard_SCH.kicad_pcb, TPA6111A2D_Protoboard_SCH.kicad_sch]
2022-10-03 Updating information.
    [ADA4610 Transimpedance Amplifier.step, LED_DRIVER_Optical_Comms_1_Reuse.kicad_pcb, LED_DRIVER_Optical_Comms_1_Reuse.kicad_sch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]
2022-12-27 Old commit + V1.1
    Building a second board with V1.1 configuration. I updated the schematics to reflect this change.
    [ADA4610 Transimpedance Amplifier.kicad_pcb, ADA4610 Transimpedance Amplifier.kicad_sch, ADA4610 Transimpedance Amplifier.ods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]
2022-12-28 commit as built 2022-12-27
    As built, working with +5V unipolar and ~100x second stage gain. IRDA signals clearly visible at 37KHz.
    [ADA4610 Transimpedance Amplifier.kicad_sch]
